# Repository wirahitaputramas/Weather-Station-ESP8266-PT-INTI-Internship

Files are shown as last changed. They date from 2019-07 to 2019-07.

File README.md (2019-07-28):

# Weather Station ESP8266

# Overview

<div align="center">
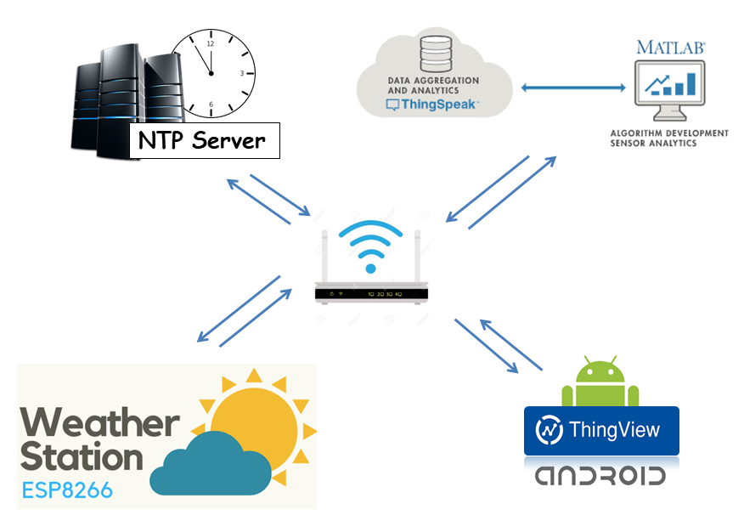
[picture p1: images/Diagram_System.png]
  
</div>
<div align="center">
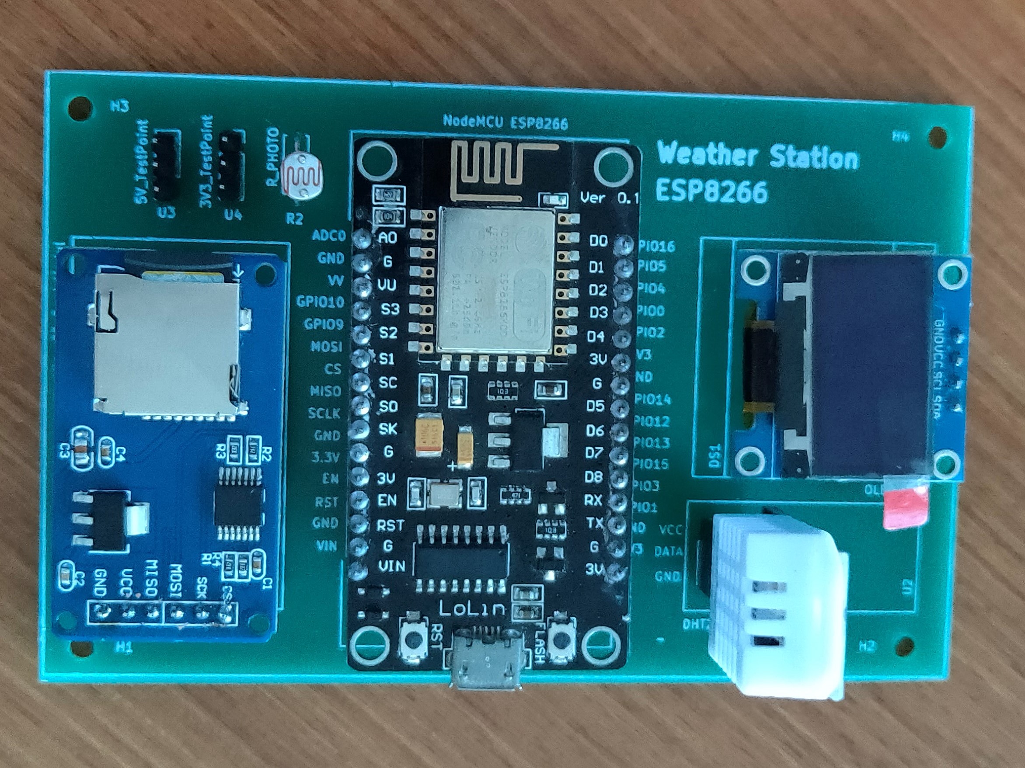
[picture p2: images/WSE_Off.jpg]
  
</div>

<div align="center">
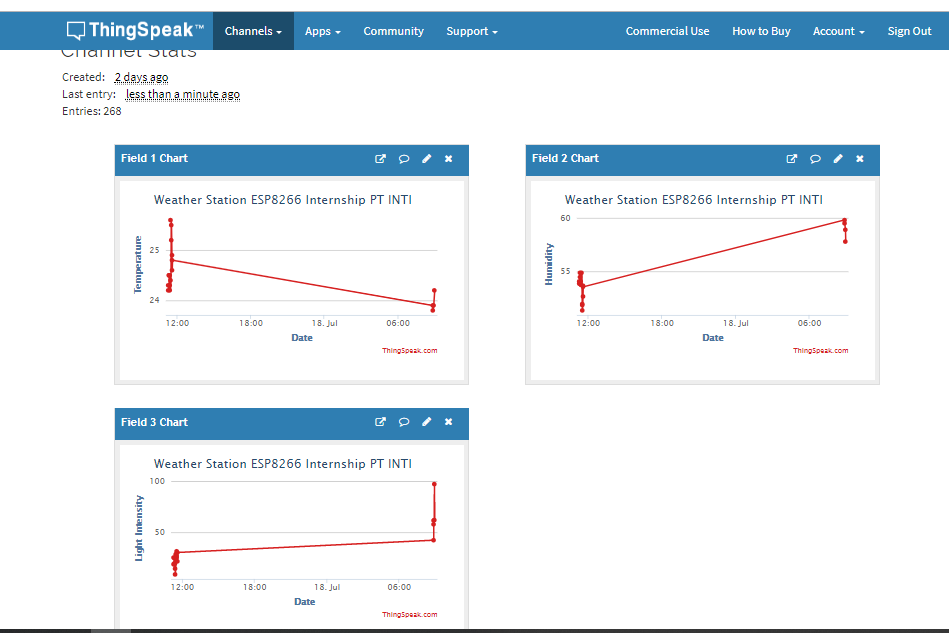
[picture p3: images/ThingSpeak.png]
  
</div>
<div align="center">
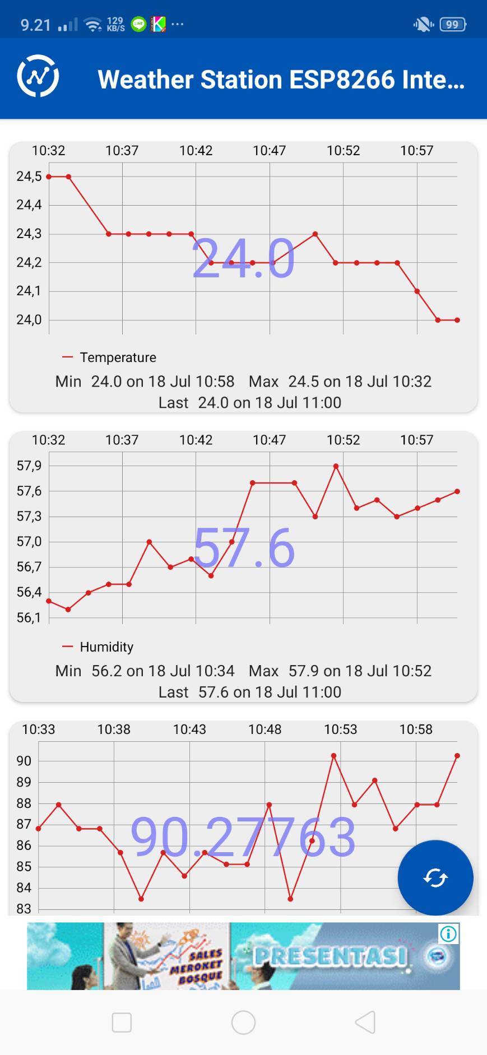
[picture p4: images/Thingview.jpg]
  
</div>

The repository includes everything needed to build an Weather Station ESP8266 (including hardware information, PCB Design, and footprint):

# What do I Need To Make One?
In this project, we assume that we still need to debug and see the output in serial monitor. So we need :
- Arduino IDE (the lastest version recommended) with serial monitor in PC or Laptop

Other Essential Things :
- Standar USB to Micro USB cable
- ESP-12E Development Board ESP8266 NodeMCU ([Pict](https://raw.githubusercontent.com/wirahitaputramas/Weather-Station-ESP8266-PT-INTI-Internship/master/images/ESP%2012E%20Development%20Board.jpg "ESP-12E Development Board ESP8266 NodeMCU"))
- OLED I2C Display 128x64 Pixel ([Pict](https://raw.githubusercontent.com/wirahitaputramas/Weather-Station-ESP8266-PT-INTI-Internship/master/images/OLED%20I2C%20Display.jpg "OLED I2C Display 128x64 Pixel"))
- SPI MicroSD Module ([Pict](https://raw.githubusercontent.com/wirahitaputramas/Weather-Station-ESP8266-PT-INTI-Internship/master/images/MicroSD%20Modul.jpg "MicroSD Module"))
- MicroSD Card (SDHC Under 32 GB recommended)
- DHT22 Modue ([Pict](https://raw.githubusercontent.com/wirahitaputramas/Weather-Station-ESP8266-PT-INTI-Internship/master/images/DHT22%20Module.jpgg "DHT22 Module"))
- LDR Photoresistor
- SMD Resistor 5 kohm

# How to Make One ?

## Testing and Prototyping on Breadboard
Before we make the circuit on the PCB, we must ensure that we choose the correct GPIO. Because of that, first of all we must hookup all component on breadboard like this picture below :
<div align="center">
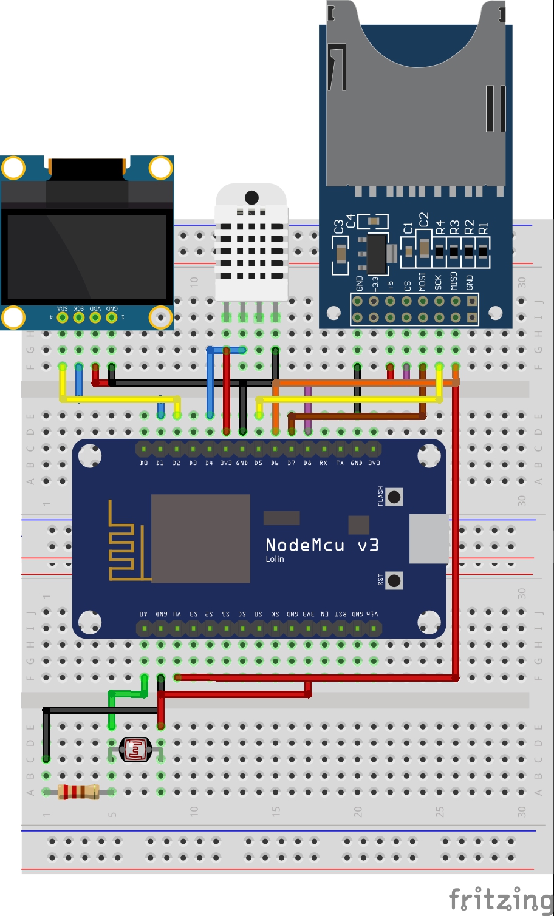
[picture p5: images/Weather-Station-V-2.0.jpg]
  
</div>

Here is the raw fritzing file ([Fritzing](https://github.com/wirahitaputramas/Weather-Station-ESP8266-PT-INTI-Internship/blob/master/Weather%20Station%20ESP8266%20on%20Breadboard.fzz "Weather Station ESP8266 on Breadboard"))

Here is the connection of each pin (exclude Vcc & GND) :
- D1 or GPIO5 to OLED SCL
- D2 or GPIO4 to OLED SDA
- D4 or GPIO2 to DHT22 IO (Data)
- D5 or GPIO14 to microSD SCLK
- D6 or GPIO12 to microSD MISO
- D7 or GPIO13 to microSD MOSI
- D8 or GPIO15 to microSD CS
- A0 or ADC0 to LDR Photoresistor

After finish the wiring, just prepare to upload the arduino whole program. We will modify any part of the source code in this repository

1. make sure that you have included the NTP Library from Fabrice Weinberg in the same folder with .ino file. Here is the [NTP Library Fabrice Weinberg](https://github.com/arduino-libraries/NTPClient.git "NTP Library Fabrice Weinberg")

2. Write down your WiFi Accses Point identity in IoT Property Block Code

```
/* IoT Property */
#include <ESP8266WiFi.h>
const char *ssid =  "SSID";     // replace with your wifi ssid and wpa2 key
const char *pass =  "PASS";
WiFiClient client;
```
3. Make your project channel in Thingspeak platform. Allocate three fields to store three different sensor reading data. After that get your channel ID and API key of your project channel. In the Screenshot below, the blue scratch is the channel ID, and the red scratch is the API Key
<div align="center">
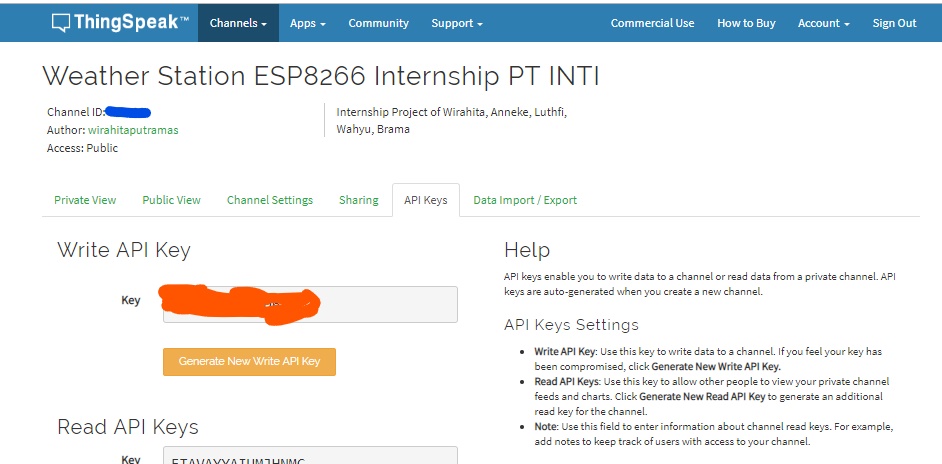
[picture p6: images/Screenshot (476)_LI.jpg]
  
</div>

Write down your Thingspeak Channel identity in Thingspeak Property Block Code in the source code.ino
```
/* Thingspeak Property */
#include <ThingSpeak.h>
unsigned long myChannelNumber = 823396; //Replace with your channel number
const char * myWriteAPIKey = "API KEY"; //Replace with your API key
/* End of Thingspeak Property */
```

4. Make sure all of pin assign in the source code.ino related to your wiring on breadboard

5. After finish uploading the program. Open the serial monitor and set the baud rate at 115200. Make sure there's no "nan" value. The nan value sometimes appear at DHT22 reading value. To Fix that, just try to plug and unplug again the DHT22 until the exact value appear, or you can trigger the DHT22 by connecting the Vcc pin to 5V

## PCB Desain, Assembly The Final Design, And Run the Weather Station on PCB

After the Prototyping on breadboard finish, now we can design the PCB on KiCad. 

1. First you need to make the Schematic or diagram of your circuit including the connection between each pin in ESP8266 and all the others component.

In this repo, you can get all file you need if you just want to skip this step. Find all .lib files. Those are your symbol schematic library. Our team have made those symbols from the scratch by seeing the datasheet and the real component. But we strongly recommended to learn and try make your own symbol because sometimes the symbol library from the other author doesn't match with your real component, usually it's pin arrangement. This is our schematic
<div align="center">
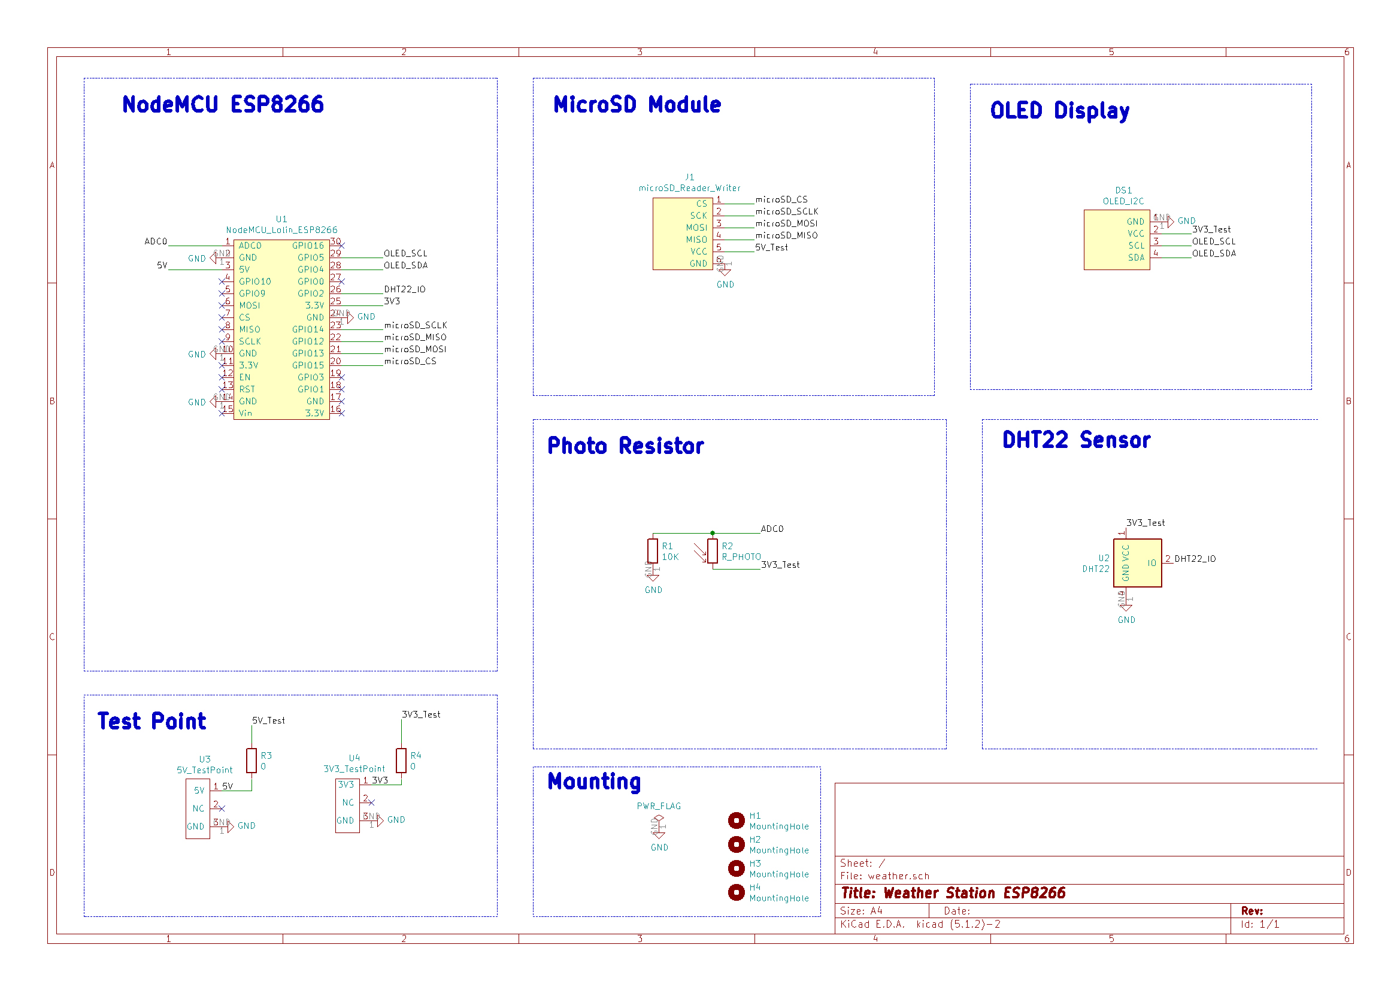
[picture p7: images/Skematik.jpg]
  
</div>

Use the label method instead of wiring method to make connection between each pin and don't forget to give some outline and comment information

2. Test The connection, and if no error, assign the footprint of each component
In this repo, we have included all footprint of the project, so you can just find the .preety folder and use that. Please note that our concept in this project is just soldering some female pin socket instead of directly solder each pin of component. So in the future, if the component broken you can easily replace with the other new one.

3. Placing and Tracking the PCB
Actually, this process depend on your own preference in placing and route the PCB. It isn't a problem if you try this step and find that your PCB is different with our PCB below, because the importnt things is all ratnest disappear and all the pin connection is right

<div align="center">
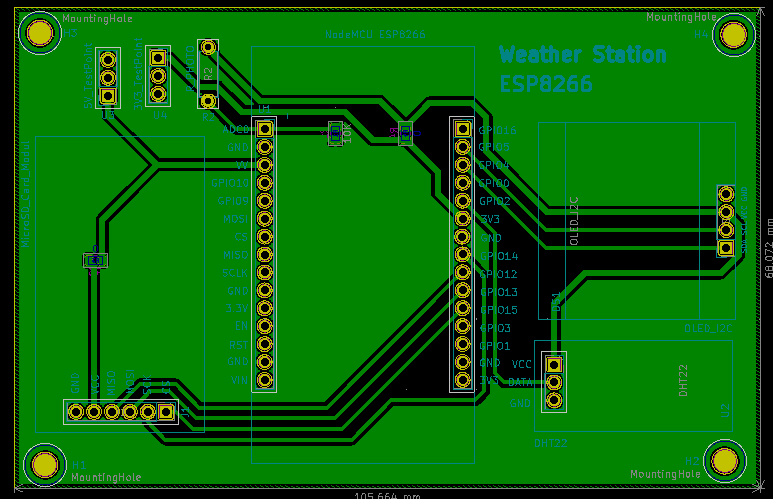
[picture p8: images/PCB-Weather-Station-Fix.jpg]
  
</div>

We choose a single layer instead of double layer because in our place double layer PCB more exspensive even when you compare with a huge single layer PCB. And also in our place, The manufacture and Printing Machine only support minimum track size at 0.6 mm and hole or drill diameter at 0.4 mm

4. After Finish the PCB. Generate the Greber File (as already available in this repo). Those picture below are some configuration to generate the gerber and drill file of our PCB
<div align="center">
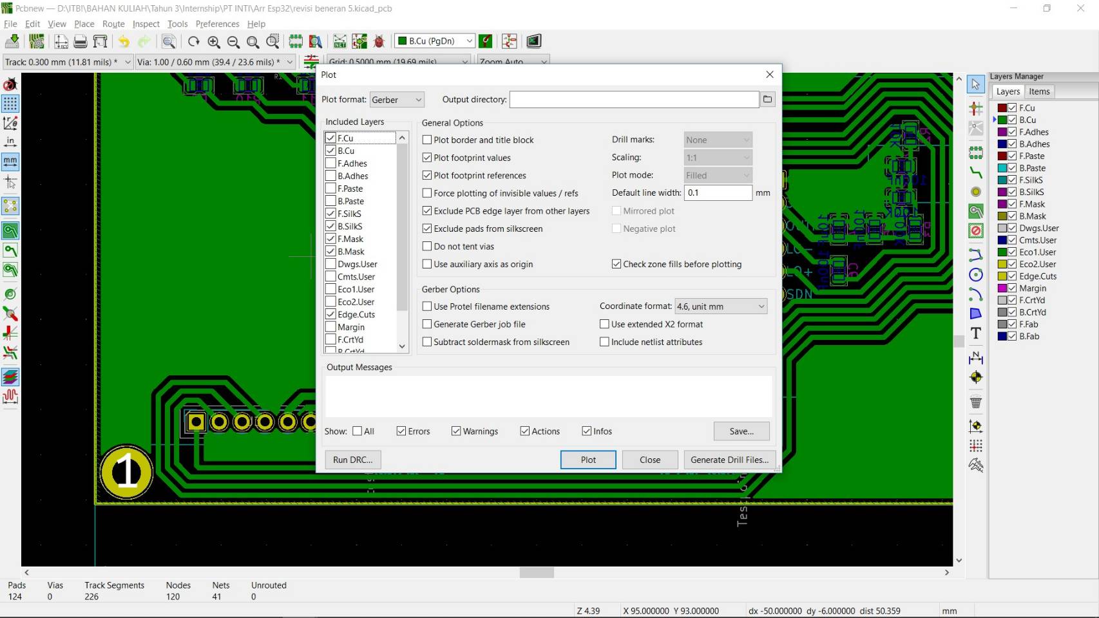
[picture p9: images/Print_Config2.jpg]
  
</div>
<div align="center">
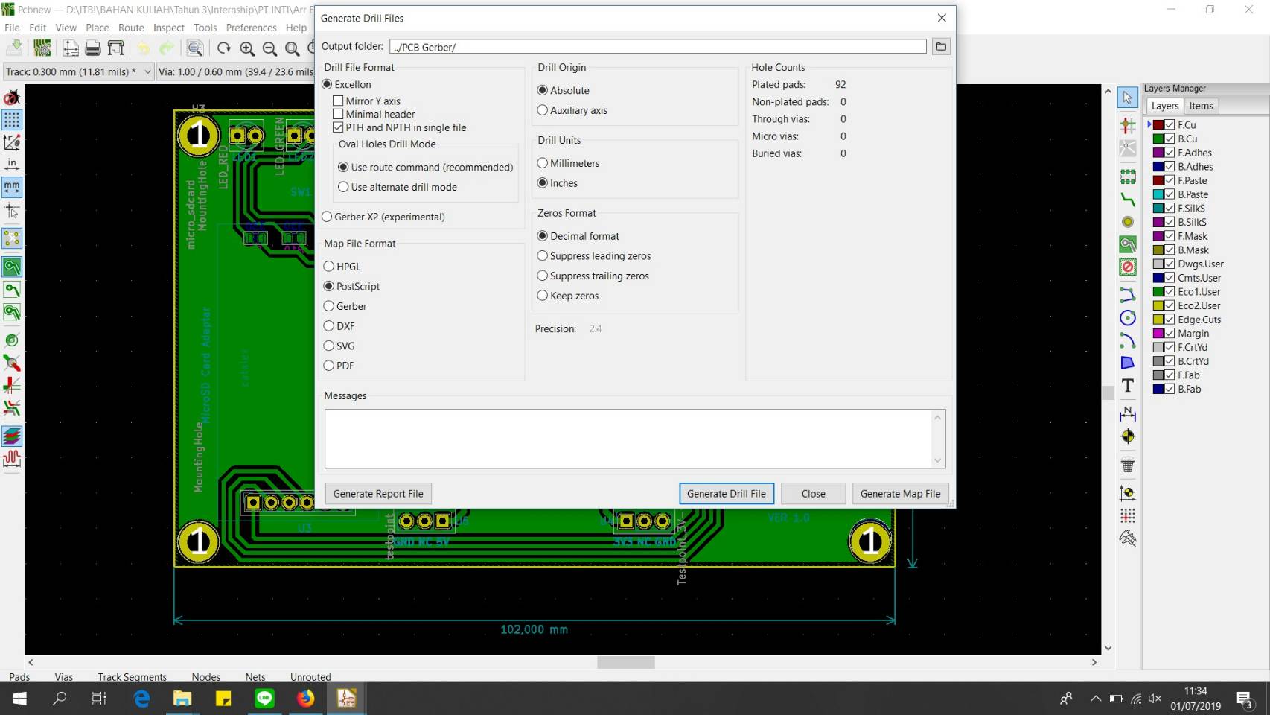
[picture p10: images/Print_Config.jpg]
  
</div>

5. Print the PCB with Gerber File. Actually I just give those gerber and drill file and don't know the exact process of PCB printing. But i see the PCB printing employee use corel draw to process the greber file.

This first image is our PCB before soldering process
<div align="center">
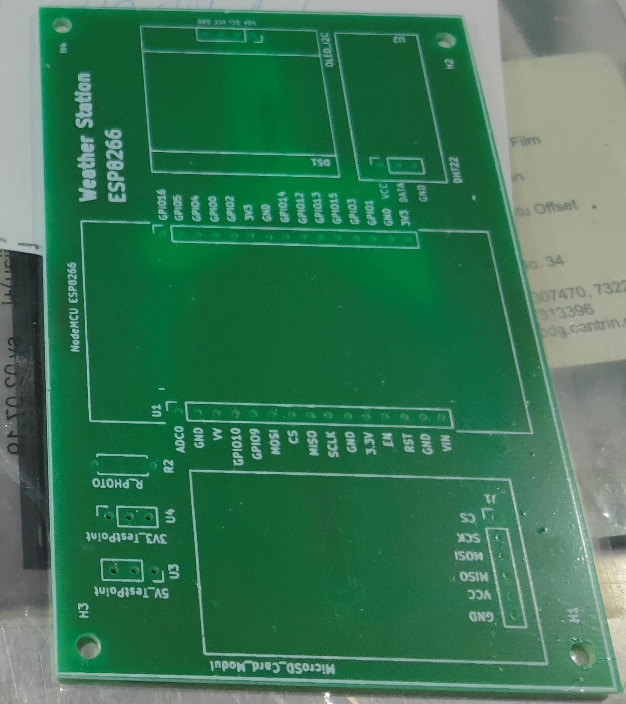
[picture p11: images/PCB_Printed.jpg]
  
</div>

<div align="center">
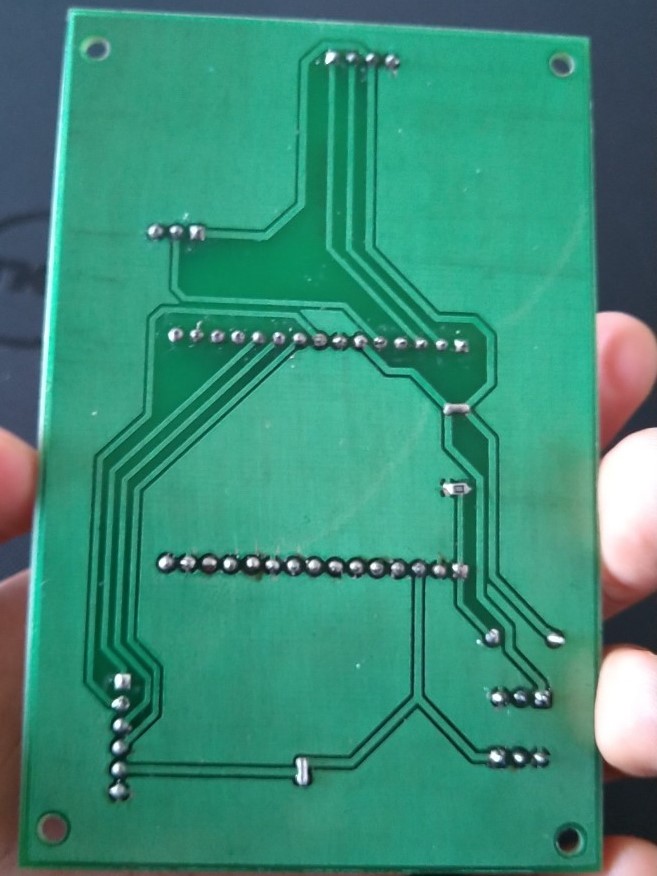
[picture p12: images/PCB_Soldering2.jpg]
  
</div>

The  image is our PCB after soldering process

<div align="center">
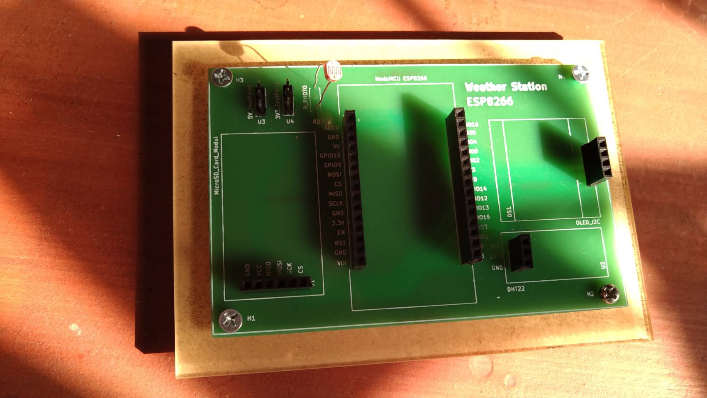
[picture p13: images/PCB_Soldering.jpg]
  
</div>

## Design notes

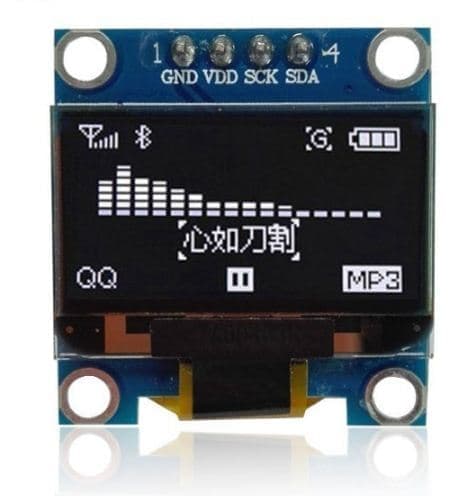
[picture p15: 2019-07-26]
images/OLED I2C Display.jpg

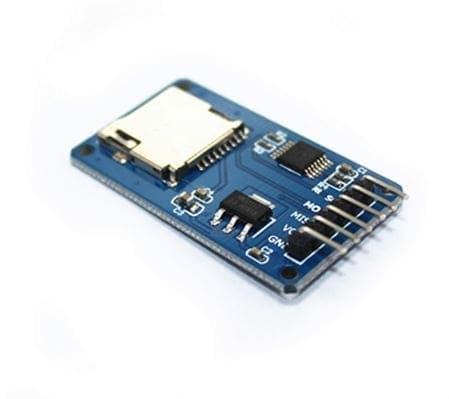
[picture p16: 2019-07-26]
images/MicroSD Modul.jpg

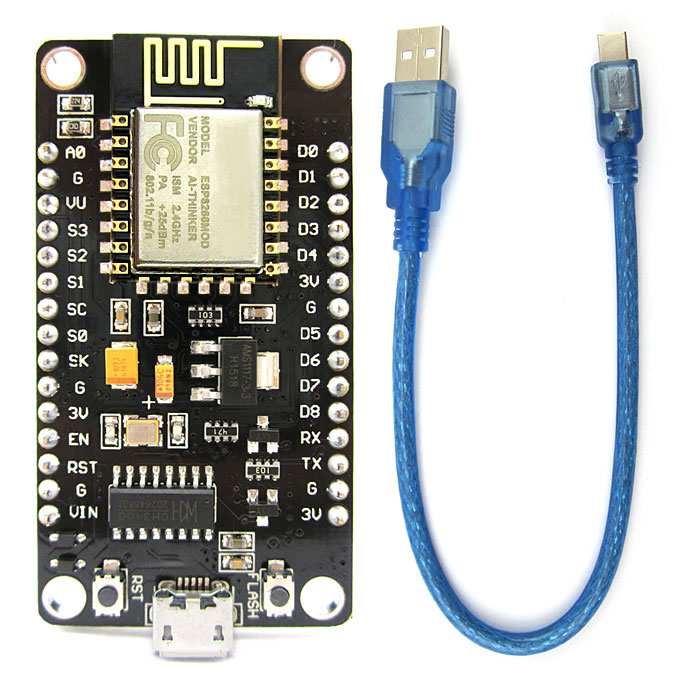
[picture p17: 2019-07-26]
images/ESP 12E Development Board.jpg

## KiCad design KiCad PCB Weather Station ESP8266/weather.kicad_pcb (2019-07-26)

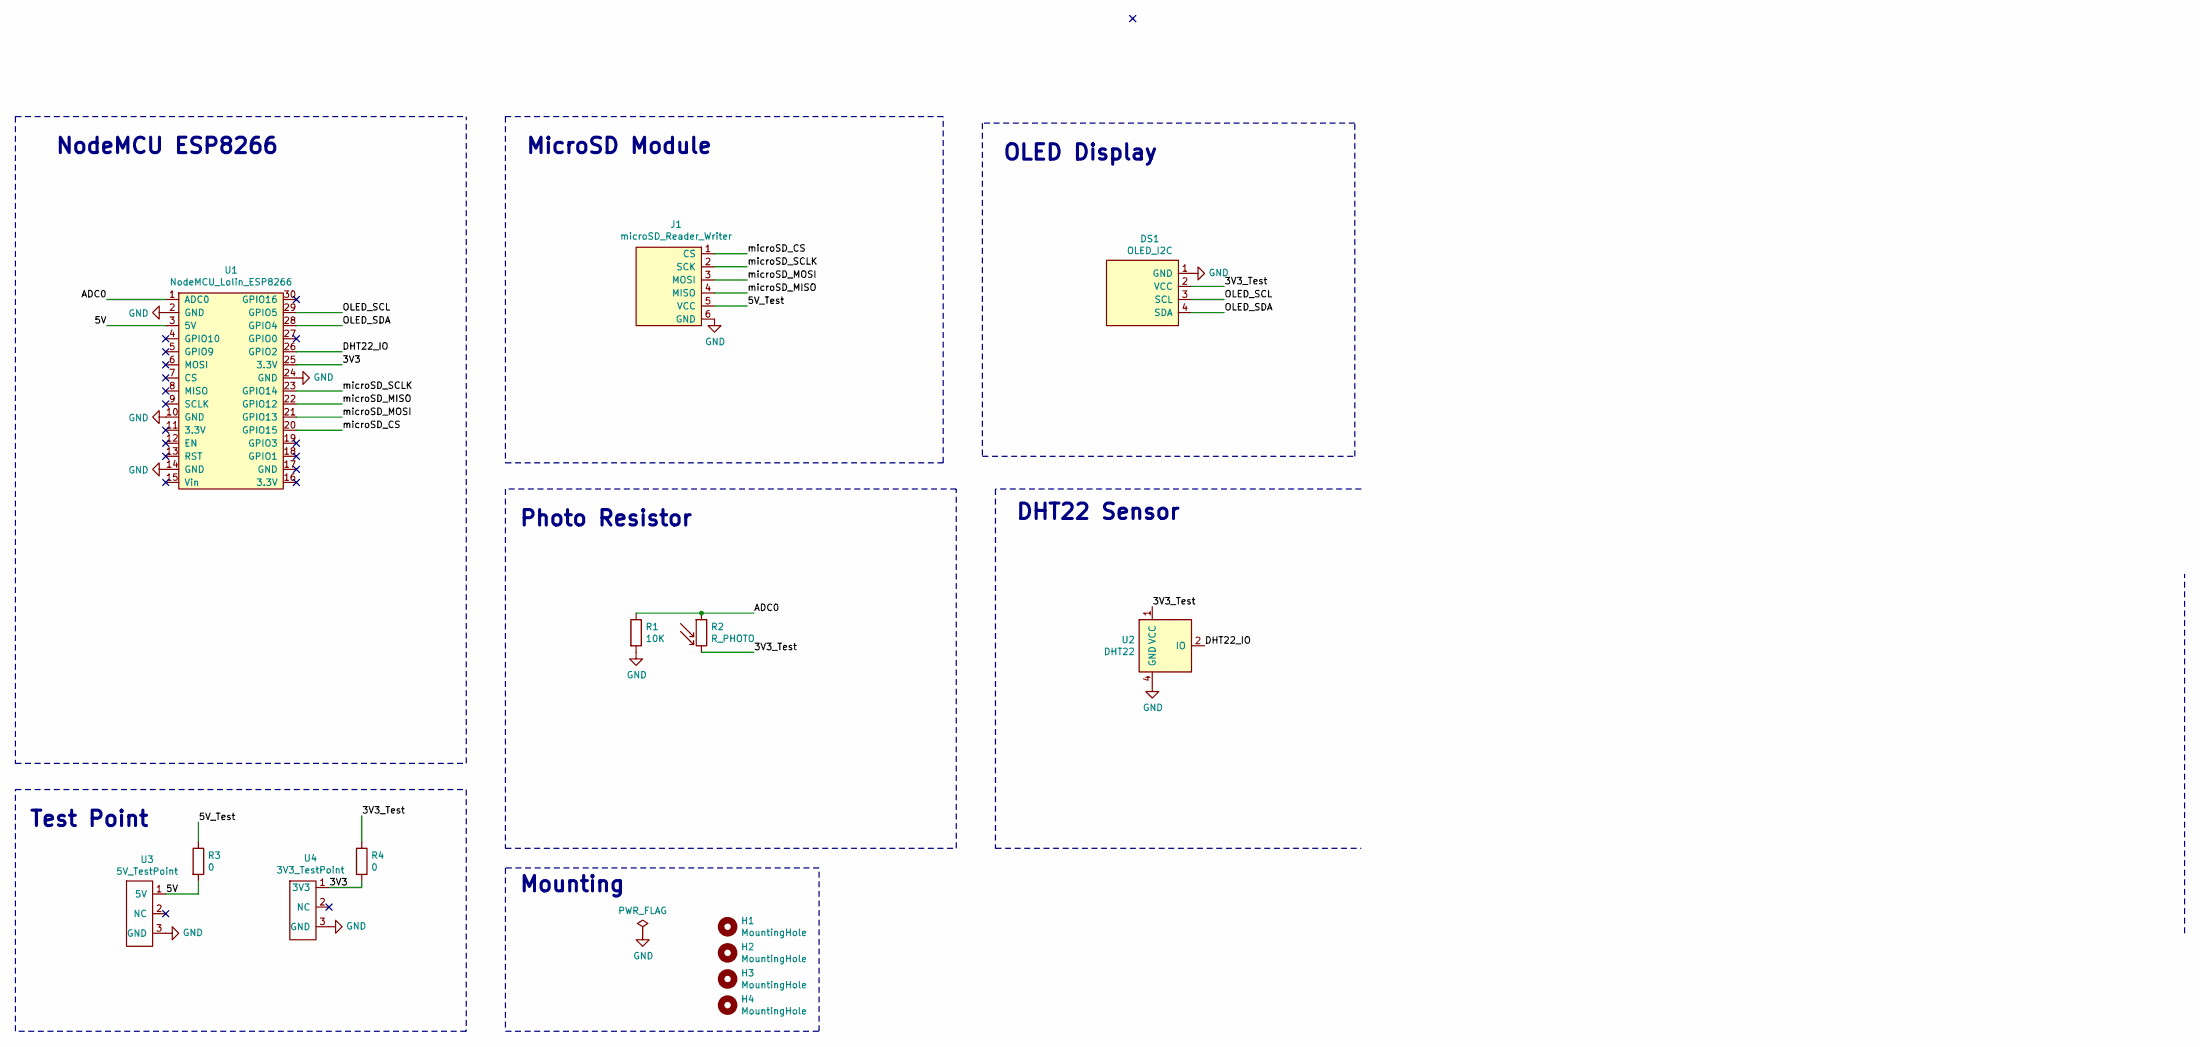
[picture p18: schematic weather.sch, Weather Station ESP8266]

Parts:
DS1: OLED_I2C
H1, H2, H3, H4: MountingHole; MountingHole_3.2mm_M3_DIN965
J1: microSD_Reader_Writer; MicroSD_Card_Modul
R1: 10K; R_0805_2012Metric
R2: R_PHOTO; PhotoResistor_THT_Horizontal
R3, R4: 0; R_0805_2012Metric
U1: NodeMCU_Lolin_ESP8266; NodeMCU_ESP8266
U2: DHT22
U3: 5V_TestPoint; PinSocket_1x03_P2.54mm_Vertical
U4: 3V3_TestPoint; PinSocket_1x03_P2.54mm_Vertical

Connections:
/3V3: R4.2, U1.25 (3.3V), U4.1 (3V3)
/3V3_Test: DS1.2 (VCC), R2.2, R4.1, U2.1 (VCC)
/5V: R3.2, U1.3 (5V), U3.1 (5V)
/5V_Test: J1.5 (VCC), R3.1
/ADC0: R1.1, R2.1, U1.1 (ADC0)
/DHT22_IO: U1.26 (GPIO2), U2.2 (IO)
/OLED_SCL: DS1.3 (SCL), U1.29 (GPIO5)
/OLED_SDA: DS1.4 (SDA), U1.28 (GPIO4)
/microSD_CS: J1.1 (CS), U1.20 (GPIO15)
/microSD_MISO: J1.4 (MISO), U1.22 (GPIO12)
/microSD_MOSI: J1.3 (MOSI), U1.21 (GPIO13)
/microSD_SCLK: J1.2 (SCK), U1.23 (GPIO14)
GND: DS1.1 (GND), J1.6 (GND), R1.2, U1.2 (GND), U1.10 (GND), U1.14 (GND), U1.24 (GND), U2.4 (GND), U3.3 (GND), U4.3 (GND)

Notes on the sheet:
NodeMCU ESP8266
MicroSD Module
OLED Display
DHT22 Sensor
Photo Resistor
Test Point
Mounting

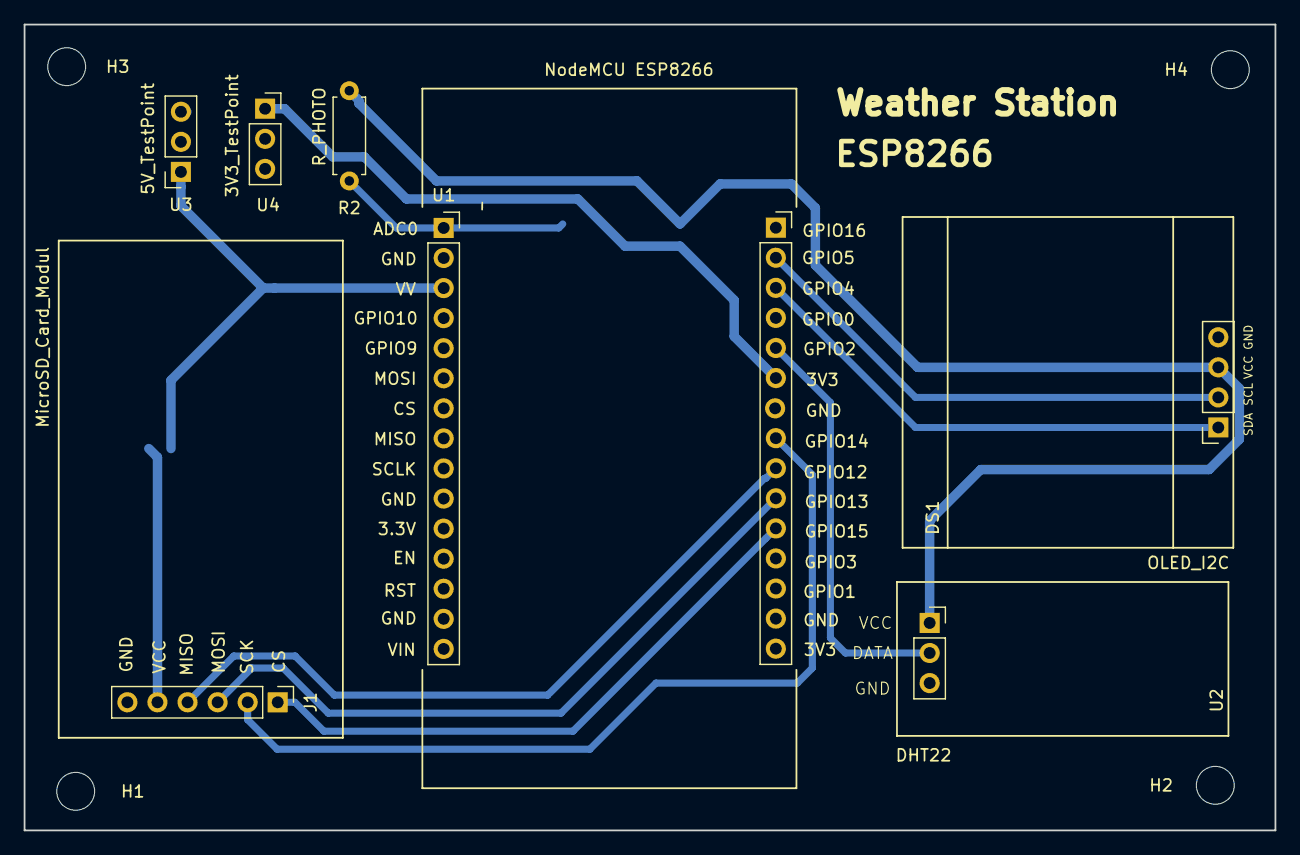
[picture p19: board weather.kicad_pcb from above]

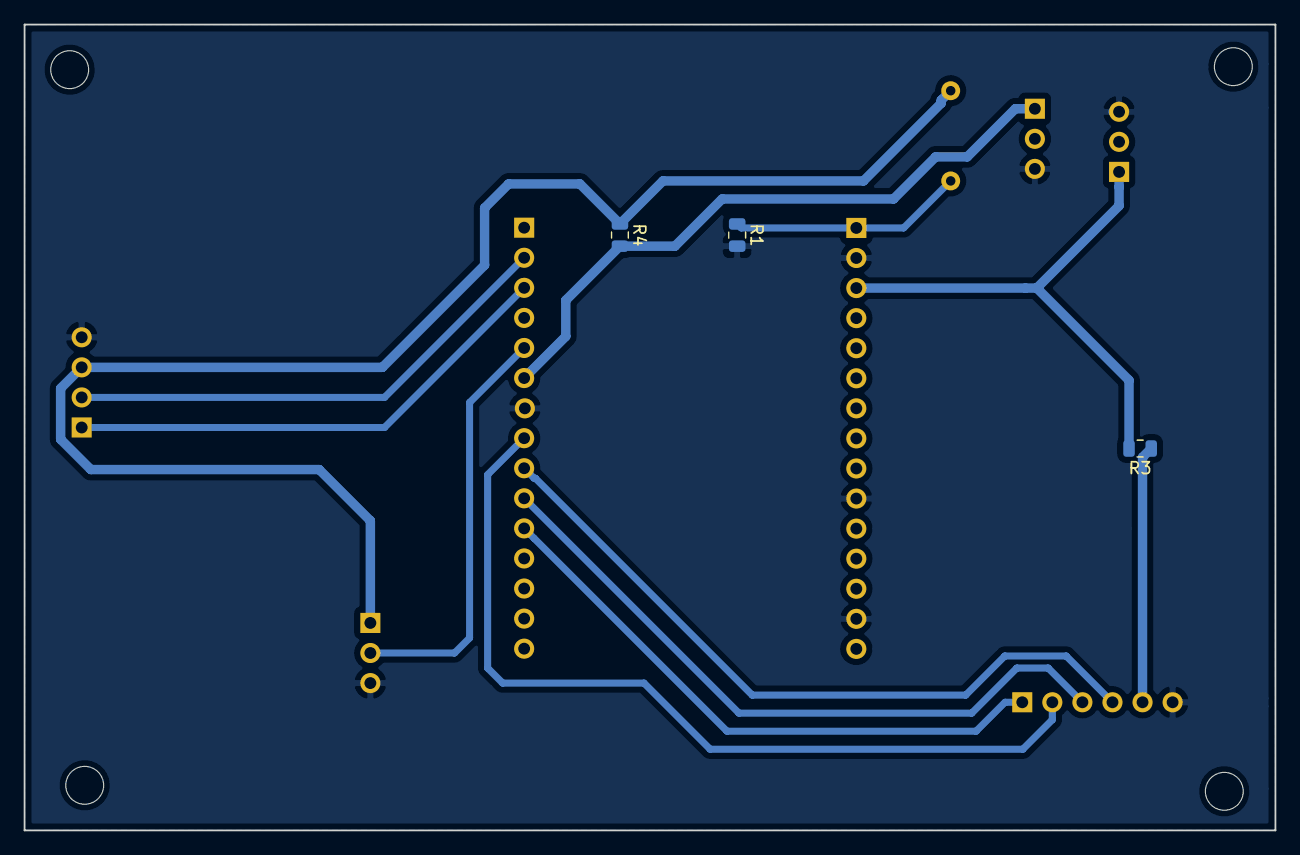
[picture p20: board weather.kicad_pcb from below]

Board: 2 copper layers, 105.7 x 68.1 mm, 14 parts (3 on the bottom side), 13 nets.

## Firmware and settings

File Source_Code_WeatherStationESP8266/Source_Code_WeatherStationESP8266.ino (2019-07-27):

/* MicroSD Module Property */
#include <SPI.h>
#include <SD.h>
File myFile;
/*End of MicroSD Module Property*/

/* DHT Sensor Property */
#include <DHT.h>

#define DHTPIN 2     // Digital pin connected to the DHT sensor (can be replaced with D4 or 2 -> because D4 = 2) 
#define DHTTYPE    DHT22     // DHT 22 (AM2302)
DHT dht(DHTPIN, DHTTYPE);
/* End of DHT Sensor Property */

/* OLED Display Property */
#include <Wire.h>
#include <Adafruit_GFX.h>
#include <Adafruit_SSD1306.h>
#include <Adafruit_Sensor.h>

#define SCREEN_WIDTH 128 // OLED display width, in pixels
#define SCREEN_HEIGHT 64 // OLED display height, in pixels  
Adafruit_SSD1306 display(SCREEN_WIDTH, SCREEN_HEIGHT, &Wire, -1); // Declaration for an SSD1306 display connected to I2C (SDA, SCL pins)
/* End of OLED Display Property */

/* IoT Property */
#include <ESP8266WiFi.h>
const char *ssid =  "SSID";     // replace with your wifi ssid and wpa2 key
const char *pass =  "PASS";
WiFiClient client;

/* Thingspeak Property */
#include <ThingSpeak.h>
unsigned long myChannelNumber = 823396; //Replace with your channel number
const char * myWriteAPIKey = "API KEY"; //Replace with your API key
/* End of Thingspeak Property */

/* NTP Client Property */

#include "NTPClient.h" // this is external library from NTP library Fabrice Weinberg (https://github.com/arduino-libraries/NTPClient.git). Put this library in the same folder with this .ino file
#include <WiFiUdp.h> //handles sending and receiving of UDP packages
WiFiUDP ntpUDP;
NTPClient timeClient(ntpUDP);
String date_time;
/*End of NTP Client Property */

/* End of IoT Property */

/* LDR Sensor Property */
int sensorPin = A0;    // input for LDR
int sensorValue2 = 0;  // variable to store the value coming from sensor LDR
#define MAX_ADC_READING     1023
#define ADC_REF_VOLTAGE     5.0
#define REF_RESISTANCE      10000
#define LUX_CALC_SCALAR     123235178.3654270
#define LUX_CALC_EXPONENT   -1.604568157
/* End of LDR Sensor Property */



void setup() {


  Serial.begin(115200); //open serial monitor on baud rate 115200

  dht.begin(); //set up sensor DHT //Set up OLED Display

  /*OLED Display Set up*/
  if(!display.begin(SSD1306_SWITCHCAPVCC, 0x3C)) {
    Serial.println(F("SSD1306 allocation failed"));
    for(;;); 
  }
  delay(2000);
  display.clearDisplay();
  display.setTextColor(WHITE);
  /*End of OLED Display Set up*/
  
  /*MicroSD Module Set up*/ 
  delay(5000); //delay to slow down the printing process on serial monitor
  Serial.print("Initializing SD card...");

  if (!SD.begin(15)) {
    Serial.println("initialization failed!");
    return;
  }
  Serial.println("initialization done.");
  /*End of MicroSD Module Set up*/

  Serial.println("Connecting to ");
       Serial.println(ssid);
 
 
       WiFi.begin(ssid, pass);
 
      while (WiFi.status() != WL_CONNECTED) 
     {
            delay(500);
            Serial.print(".");
     }
      Serial.println("");
      Serial.println("WiFi connected");

      ThingSpeak.begin(client);  // Initialize ThingSpeak

      timeClient.begin();
      // Set offset time in seconds to adjust for your timezone, for example:
      // GMT +1 = 3600
      // GMT +8 = 28800
      // GMT -1 = -3600
      // GMT 0 = 0
      timeClient.setTimeOffset(25200);
}

void loop() {
  
  timeClient.update();
  date_time = timeClient.getFormattedDate();
  Serial.println(date_time);
  
  delay(5000);
  //read temperature and humidity
  float t = dht.readTemperature();
  float h = dht.readHumidity();

  //read LDR sensor
  sensorValue2 = analogRead(sensorPin);
  delay(100);

  float resistorVoltage, ldrVoltage;
  float ldrResistance;
  float ldrLux;
  resistorVoltage = (float)sensorValue2 / MAX_ADC_READING * ADC_REF_VOLTAGE;
  ldrVoltage = ADC_REF_VOLTAGE - resistorVoltage;
  ldrResistance = ldrVoltage/resistorVoltage * REF_RESISTANCE;
  ldrLux = LUX_CALC_SCALAR * pow(ldrResistance, LUX_CALC_EXPONENT);
  //Serial.print("Light Intensity :"); Serial.print(ldrLux ); Serial.println(" lux");

  //clear display
  display.clearDisplay();
  
  // display temperature
  display.setTextSize(1);
  display.setCursor(0,0);
  
  Serial.print("Temperature: ");
  Serial.print(t);
  Serial.println(" degrees Celcius");
   
  display.print("Temperature: ");
  display.setTextSize(1);
  display.setCursor(0,10);
  display.print(t);
  display.print(" ");
  display.setTextSize(1);
  display.cp437(true);
  display.write(167);
  display.setTextSize(1);
  display.print("C ");
  
  // display humidity
  display.setTextSize(1);
  display.setCursor(0, 20);
   
  Serial.print("Humidity: ");
  Serial.print(h);
  Serial.println(" %");
  
  display.print("Humidity: ");
  display.setTextSize(1);
  display.setCursor(0, 30);
  display.print(h);
  display.print(" % "); 

  //display LDR
  display.setTextSize(1);
  display.setCursor (0,40);

  Serial.print("Light Intensity : ");
  Serial.print(ldrLux);
  Serial.println(" lux");
  
  display.print("Light Intensity: ");
  display.setTextSize(1);
  display.setCursor(0, 50);
  display.print(ldrLux);
  display.print("lux");
  
  display.display();

   // open the file. note that only one file can be open at a time,
  // so you have to close this one before opening another.
  myFile = SD.open("WeatherData.txt", FILE_WRITE);

  // if the file opened okay, write to it:
  if (myFile) {
    Serial.println("");
    Serial.println("Writing to WeatherData.txt...");

    myFile.println(date_time);

    //writing data to MicroSD
    myFile.print("Humidity : ");
    myFile.print(h);
    myFile.println(" %");
    myFile.print("Temperature : ");
    myFile.print(t);
    myFile.println(" C");
    myFile.print("Light Intensity : ");
    myFile.print(ldrLux);
    myFile.println(" lux");

    myFile.println(" ");
    // close the file:
    myFile.close();
    Serial.println("done writing.............");
  } else {
    // if the file didn't open, print an error:
    Serial.println("error opening WeatherData.txt");
  }

  // re-open the file for reading:
  Serial.println("");
  myFile = SD.open("WeatherData.txt");
  if (myFile) {
    Serial.println("Reading WeatherData.txt .........");

    // read from the file until there's nothing else in it:
    while (myFile.available()) {
      Serial.write(myFile.read());
    }
    // close the file:
    myFile.close();
  } else {
    // if the file didn't open, print an error:
    Serial.println("error opening WeatherData.txt");
  }

  Serial.println("done reading..........");

  long int data = ThingSpeak.writeField(myChannelNumber, 1, t, myWriteAPIKey);
  if(data == 200){
    Serial.println("Temp Channel update successful.");
  }
  else{
    Serial.println("Problem updating Temp channel. HTTP error code " + String(data));
  }  
  delay(20000); // Wait 20 seconds to update the channel again

  data = ThingSpeak.writeField(myChannelNumber, 2, h, myWriteAPIKey);
  if(data == 200){
    Serial.println("Humid Channel update successful.");
  }
  else{
    Serial.println("Problem updating Humid channel. HTTP error code " + String(data));
  }
 delay(20000); // Wait 20 seconds to update the channel again

  data = ThingSpeak.writeField(myChannelNumber, 3, ldrLux, myWriteAPIKey);
  if(data == 200){
    Serial.println("LDR Channel update successful.");
  }
  else{
    Serial.println("Problem updating LDR channel. HTTP error code " + String(data));
  }  
  delay(20000); // Wait 20 seconds to update the channel again
  
  
}
  
